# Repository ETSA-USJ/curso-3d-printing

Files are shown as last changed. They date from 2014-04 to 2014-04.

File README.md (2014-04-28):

Curso 3D printing: Montaje de una Prusa Mendel IT2
============================================

Curso 2031-14
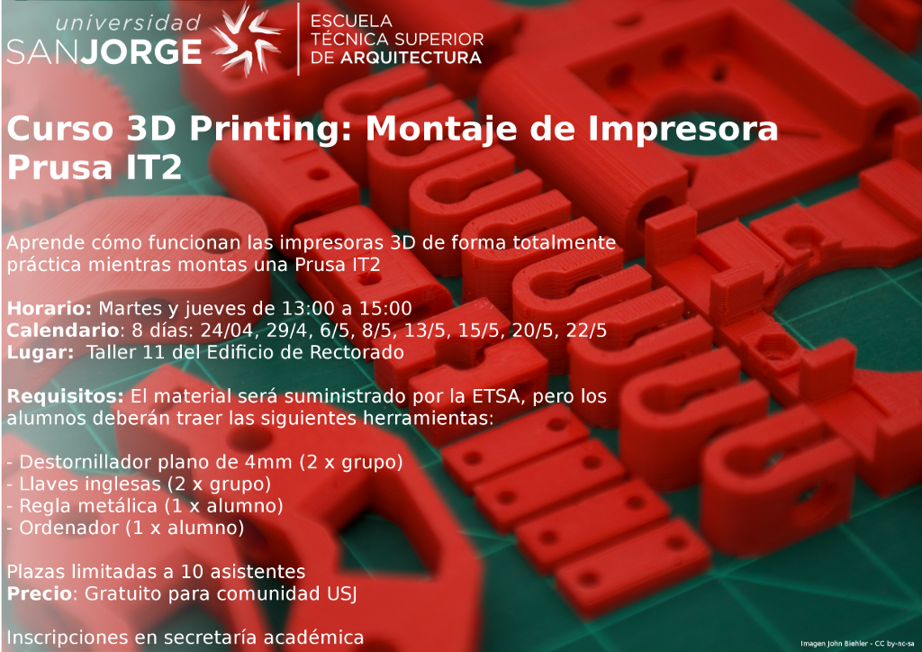
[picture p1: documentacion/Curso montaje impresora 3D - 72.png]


### Responsables del curso
* David Álvarez
* Javier Álvarez
* Carlos Cámara
* Antonio Estepa

## Documentación

* [Piezas Prusa Mendel IT2 (Fuente: Clone Wars)](http://www.reprap.org/wiki/Clone_wars:_Prusa_Iteraci%C3%B3n_2)
* [Guía de montaje (Fuente: IEA Robotics)](http://www.iearobotics.com/wiki/index.php?title=Guia_de_montaje_de_la_Prusa_2)
* [Thingiverse](http://www.thingiverse.com)

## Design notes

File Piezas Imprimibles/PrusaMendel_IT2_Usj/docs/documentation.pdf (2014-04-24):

## Prusa Mendel iteration 2 Documentation

ThingDoc

November 16, 2011

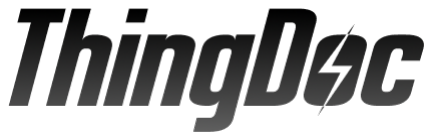
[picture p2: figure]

Prusa Mendel is simplified version of Mendel form RepRap project. RepRap is open source 3D printer.

## Contents

## 1 Bill of Materials

List of things you need to build the machine divided by categories.

### 1.1 Rods and Bars

- 1x Idler

### 1.2 Nuts&bolts

- 3x 608 skate bearing
- 4x M4 nut
- 3x M3 10mm screw
- 2x M4 25mm screw
- 1x M8 hobbed bolt
- 8x M3 15mm screw with HEX head
- 2x M3 10mm screw with hex head
- 1x M3 25mm screw
- 1x M3 grub screw
- 2x M3 25mm screw with HEX head
- 12x M3 nut
- 73x M8 washer
- 74x M8 nut
- 29x M3 washer
- 1x M3 10mm screw with flat head
- 2x M3 40mm screw

### 1.3 Printed

- 1x Extruder body
- 8x Bar clamp
- 4x Y bushing
- 2x Frame vertex
- 1x Y motor bracket
- 1x Small extruder gear

- 2x Rod clamp
- 4x Frame vertex with foot
- 1x Large extruder gear
- 2x Belt clamp
- 1x Extruder Idler
- 1x Z motor mount
- 1x X carriage

## 2 Things Overview

List of things and their descriptions.

### 2.1 Coupling tube

20mm long piece of PVC tube. 5mm inside diameter, 8mm outside diameter.

### 2.2 Frame triangle

Two triangle parts which will later form a frame.

### 2.3 Frame with axes

Frame with all axes mounted

### 2.4 Frame vertex

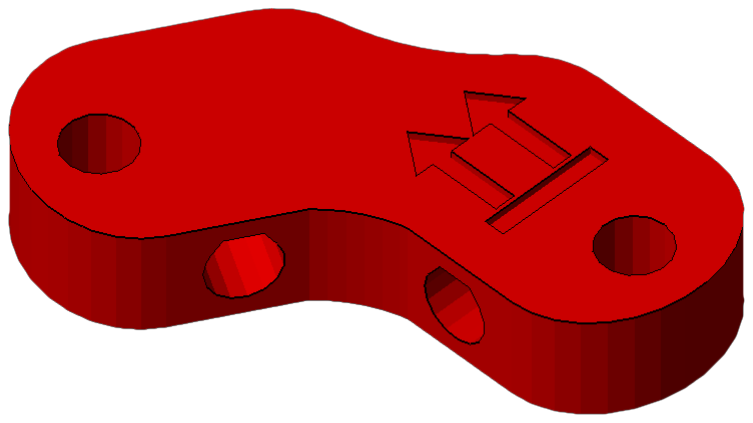
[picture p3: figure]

### 2.5 Frame

Frame for adding all of the other parts There is a triangle on each side of the Prusa RepRap. You will need to make two of these and then connect them together (in the next steps) to form the Prusa frame. Each side is an equilateral triangle with a frame vertex on each corner. You can use either footed or non-footed vertices to build this. (The footed ones look better, but are not critical.) The instructions assume you are using footed vertices.

### 2.6 Y motor bracket

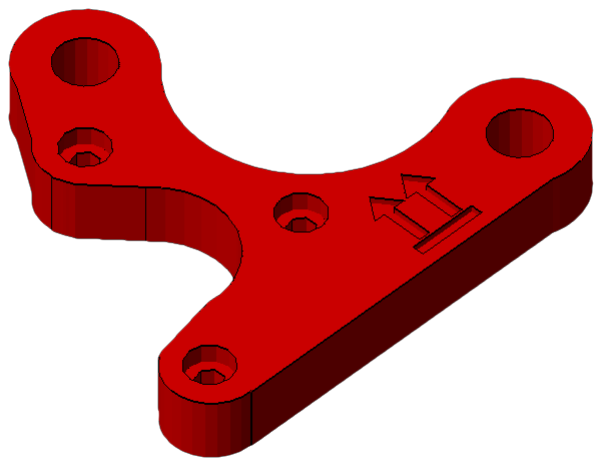
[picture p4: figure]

### 2.7 Belt clamp

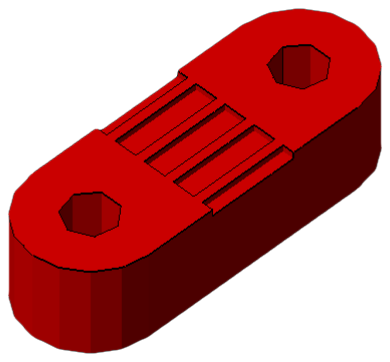
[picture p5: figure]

### 2.8 M8 hobbed bolt

### 2.9 Extruder Idler

Extruder idler

### 2.10 Frame with Y axis

Frame with Y axis mounted

### 2.11 Y bushing

### 2.12 Bar clamp

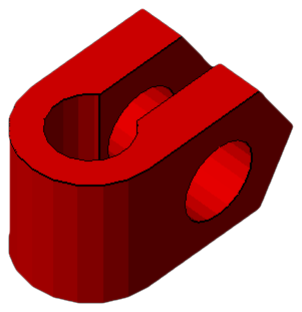
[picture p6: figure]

### 2.13 XZ axis

Assembled XZ axis

### 2.14 Large extruder gear

### 2.15 Frame vertex with foot

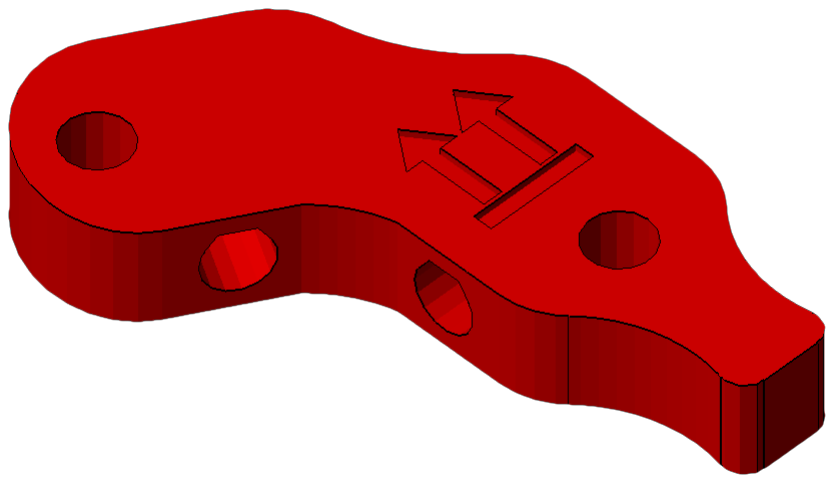
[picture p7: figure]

### 2.16 X end motor

### 2.17 Extruder body

Extruder body

### 2.18 Small extruder gear

### 2.19 Extruder spring

Spring used for idler on extruder.

### 2.20 Printable Bushing

### 2.21 X carriage

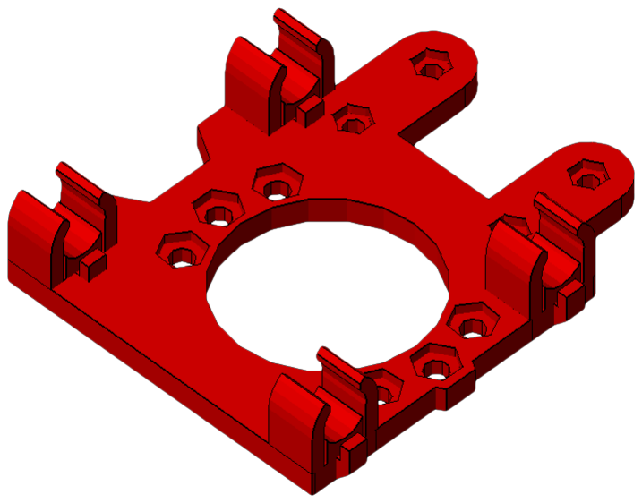
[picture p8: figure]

### 2.22 X end idler

### 2.23 Rod clamp

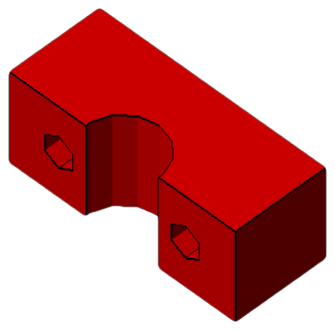
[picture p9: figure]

### 2.24 Z motor mount

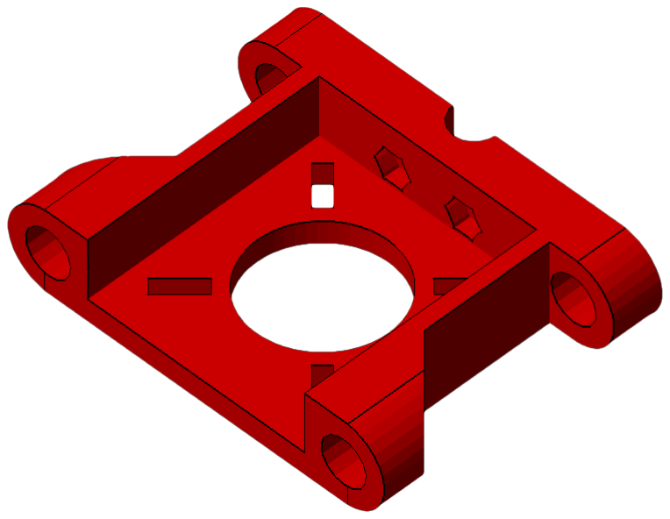
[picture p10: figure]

### 2.25 Endstop holder

### 2.26 Bushing

### 2.27 Idler

Small M8 rod

### 2.28 Pulley

### 2.29 Coupling

### 2.30 Y axis

Assembled Y axis

### 2.31 Bearing guide

Helps to hold belt aligned on the bearing.

### 2.32 Carriage

X-carriage with mounted extruder

### 2.33 Extruder

Extruder

## 3 Assembly Instructions

### 3.1 Assemble Small extruder gear

Things needed:

- 1x M3 nut
- 1x M3 grub screw

Steps:

1. Insert nut into cavity in printed gear.
2. Tighten the grub screw a bit, just to hold in place.

### 3.2 Assemble M8 hobbed bolt

Steps:

1. Use thread cutting bit in electric screwdriver ...

### 3.3 Assemble Large extruder gear

Things needed:

- 1x M8 hobbed bolt

Steps:

1. Insert hobbed bolt into main hole.
2. Add some M8 washers from other side, later with their count you adjust position of hobbed part in filament path.

### 3.4 Assemble Extruder Idler

Things needed:

- 1x 608 skate bearing
- 1x Idler

Steps:

1. Insert piece of M8 rod into bearing.
2. Insert 608 bearing with rod into printed idler part.

### 3.5 Assemble Extruder

Things needed:

- 2x 608 skate bearing
- 1x Extruder body
- 3x M3 10mm screw
- 2x M4 nut
- 1x Small extruder gear
- 1x M3 25mm screw
- 1x NEMA17 stepper motor
- 1x Large extruder gear
- 8x M3 washer
- 1x M8 washer
- 1x Extruder Idler
- 1x M3 nut
- 2x M3 40mm screw
- 2x Extruder spring
- 2x M8 nut

Steps:

1. Take idler and insert nut into small nut-trap inside the hinge.
2. While holding the nut in place, preprare M3x25 bolt with washer and screw it into the hinge just enough to hold the nut.
3. Now take the extruder body and idler. Place idler on the hinge counterpart and com-pleately screw the M3x25 bolt. This will create secured hinge.
4. Place M4 nuts into their nut traps, secure them with piece of tape. We need them in place, since later they would be harder to access.
5. Prepare your NEMA17 stepper motor and three M3x10 screws with washers.
6. Hold motor on place and lightly tighten the screws. We need to adjust motor position later, no need to tighten it hard.
7. Place two skate bearings on ther position, they should snuggly fit in.
8. Insert prepared large gear into the body with mounted bearings.

9. Check if the alignment of hobbed part with the filament path. Adjust it accordingly with adding or removing M8 washers.
10. After adjusting, we need to fix the bolt in. So we place washer at the end of hobbed bolt and with two M8 nuts we will do locknut by tightening them against each other.
11. Check if large gear turns freely.
12. Prepare two M3x40 screws with sandwitch of washer-spring-washer.
13. Insert two M3 nuts into nut traps on top of drive mechanism.

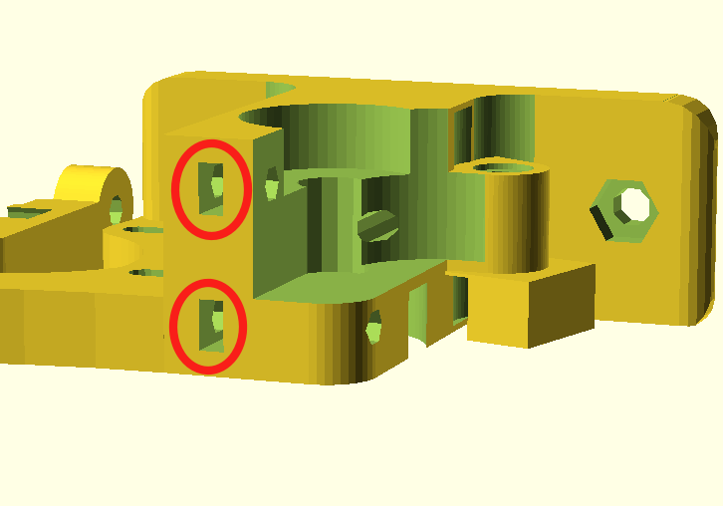
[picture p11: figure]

14. Insert prepared screws into the holes on idler. Close the idler and tighten the screws into the trapped nuts. More you tighten those screws, more pressure will be on fillament.
15. Your extruder is done.

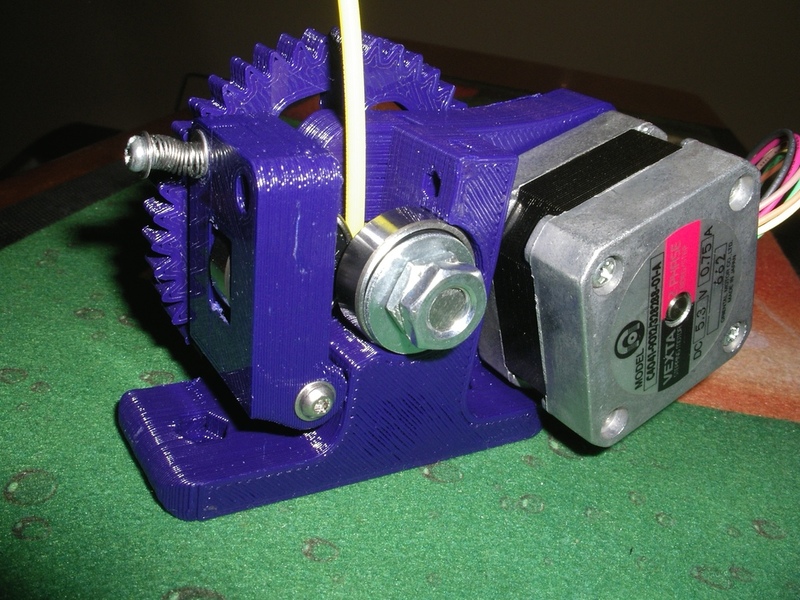
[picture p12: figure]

### 3.6 Assemble Frame triangle

Things needed:

- 1x Bar clamp
- 1x Frame vertex
- 2x Frame vertex with foot

Steps:

1. Take one of the 370mm threaded rods, and slip an M8 washer onto the middle of it.
2. Take the RP bar clamp (the U-shaped bit with the two holes) and slide the threaded rod through the two holes until the clamp sits next to the washer.
3. Slide another washer onto the rod from the other side.
4. Thread two M8 nuts onto either side of the clamp, until they are next to the washer, but do not tighten them yet.

5. Thread another two nuts on each side of the rod, followed by washers. See the picture for what it should look like.

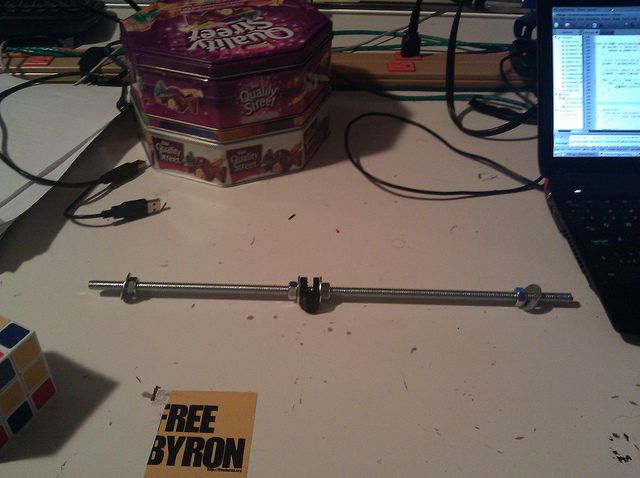
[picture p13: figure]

6. The bar clamp on the threaded rod.
7. Slide the rod through the wider bottom (footed) side of two vertices. Make sure the feet point in the same direction, and the bulge on the non-footed sides of the vertices point outwards.
8. Measure the distance. The distance between the two vertices should be 290mm (along the rod, equivalent is 11-13/32”). Get it approximately right now, we will check this again later. If you have a frame jig, place it between the two vertices and adjust the nuts until you can just barely fit the jig J1 between them.
9. Place another washer and nut on the other side of the vertex. Tighten, but not too much. We’ll need a bit of flexibility here still.
10. Take another 370mm M8 threaded rod and place a nut followed by a washer at each end.
11. Place one end of the threaded rod into the one of the two footed frame vertices. It should be in the same plane as the first threaded rod. Fix it in place with a washer and nut. You should now have two sides of the equilateral triangle.
12. Take the third piece of threaded rod and put a nut and washer on each end. Place it in the other footed vertex and fix it in place with a washer and nut. You should now have a triangle of threaded rods with two footed vertices on two of the corners, nothing in the third corner, and a bar clamp between the two vertices.
13. Take the third vertex (non-footed) and slide it onto the threaded rods in the final corner of the triangle. Measure the lengths of the three sides to make sure they are all 290mm long (along the rod from plastic part to plastic part, equivalent is 11-13/32”). Adjust the nuts to make sure this is so. Use the frame jig J1 if you have one. Once done, place a washer and nut on each of the two rods at the top of the vertex. Tighten all the outer nuts.
14. The finished frame triangle
15. You should now have a sturdy triangle with equal-length sides, two feet on the bottom, and a bar clamp between the feet. Adjust the nuts around the bar clamp (but do not crush the bar clamp together yet) until it’s approximately in the middle of the rod. Leave the nuts there loose. See the photo for what you should have at this point.

16. That’s it, that’s one of the triangles done. Repeat the entire procedure for the second triangle. It is identical to the first.

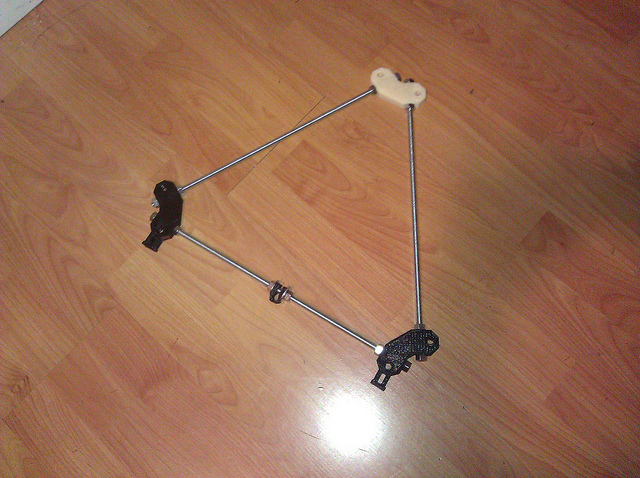
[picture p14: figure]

### 3.7 Assemble Prusa Mendel iteration 2

Things needed:

- 1x Carriage
- 1x Frame with axes

Steps:

1. Assembly info

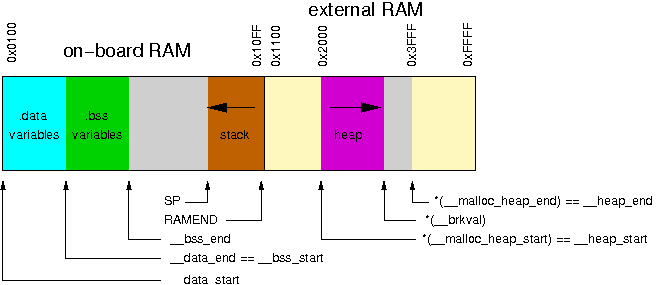
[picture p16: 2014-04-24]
Software/Arduino/Mac/Arduino 1.0.5.app/Contents/Resources/Java/hardware/tools/avr/doc/avr-libc/malloc-x2.png

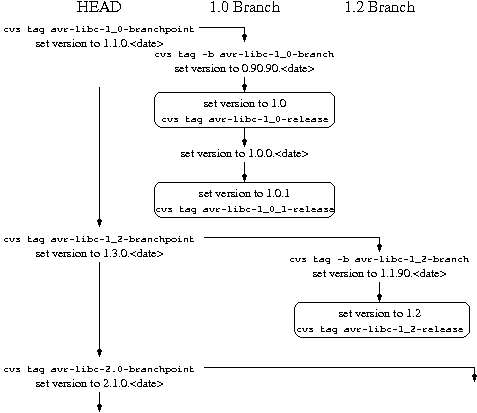
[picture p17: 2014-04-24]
Software/Arduino/Mac/Arduino 1.0.5.app/Contents/Resources/Java/hardware/tools/avr/doc/avr-libc/releases.png

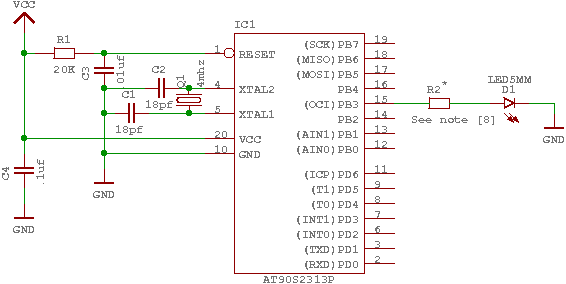
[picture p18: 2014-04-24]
Software/Arduino/Mac/Arduino 1.0.5.app/Contents/Resources/Java/hardware/tools/avr/doc/avr-libc/demo.png

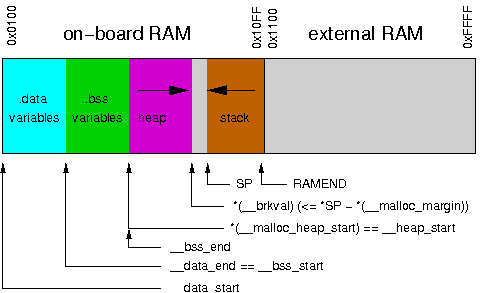
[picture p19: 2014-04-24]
Software/Arduino/Mac/Arduino 1.0.5.app/Contents/Resources/Java/hardware/tools/avr/doc/avr-libc/malloc-std.png

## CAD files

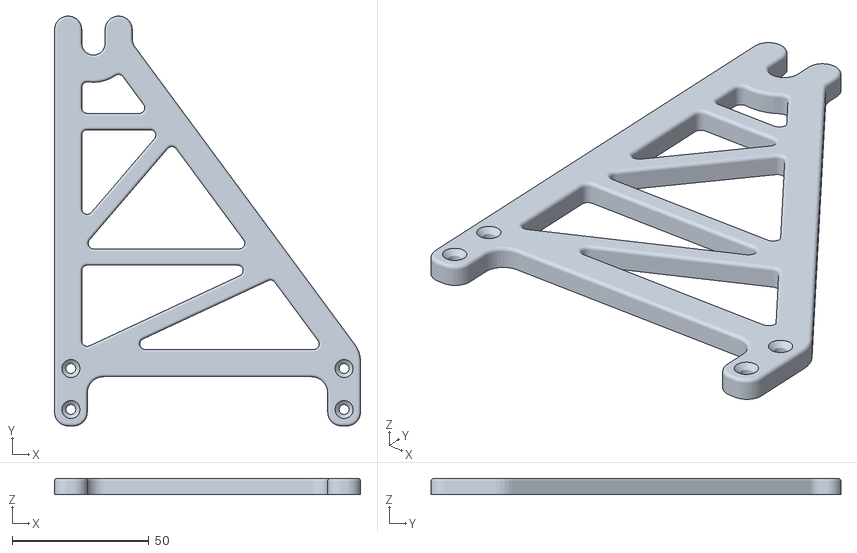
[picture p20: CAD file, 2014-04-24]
Piezas Imprimibles/Ampliaciones/Soporte Bobina/SPOOL_ARM_LEFT.stl
112.0 x 150.0 x 6.00

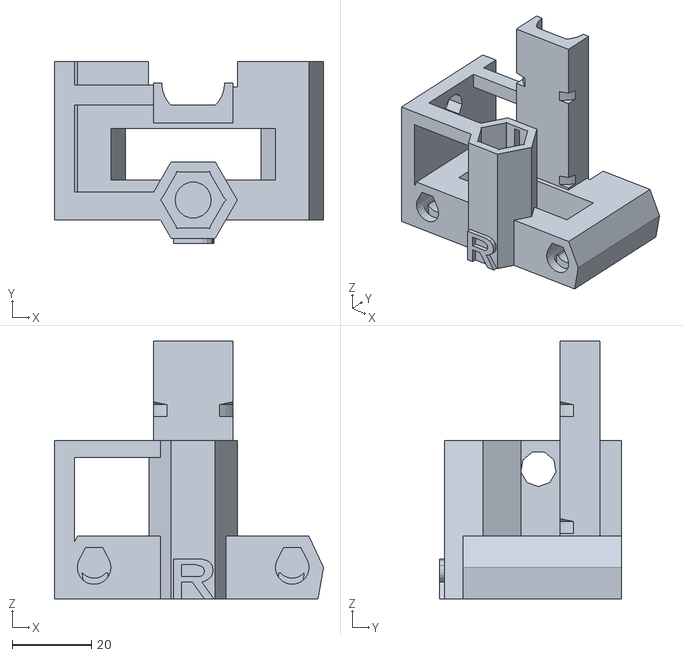
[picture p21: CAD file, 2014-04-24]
Piezas Imprimibles/PrusaMendel_IT2_Usj/metric-prusa-lm8uu/x-end-idler.stl
67.9 x 46.0 x 65.0

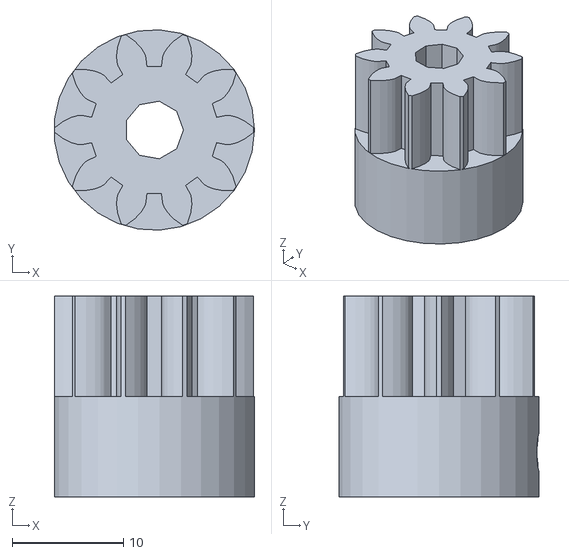
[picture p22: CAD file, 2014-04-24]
Piezas Imprimibles/PrusaMendel_IT2_Usj/metric-prusa-lme8uu/wade-small.stl
17.9 x 18.0 x 18.0

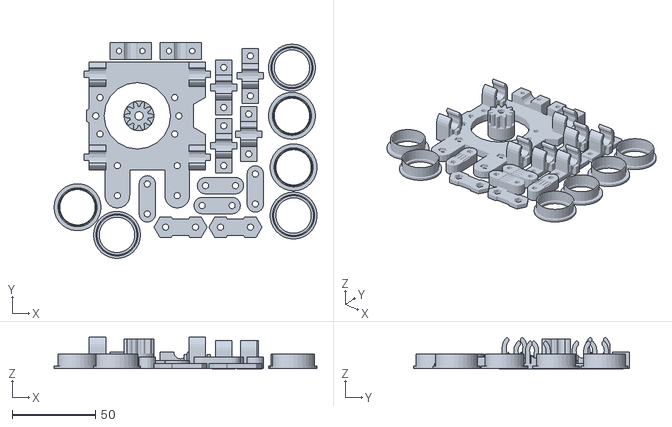
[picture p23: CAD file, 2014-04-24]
Piezas Imprimibles/PrusaMendel_IT2_Usj/metric-prusa/mendel-plate-4.stl
158.2 x 129.7 x 19.0

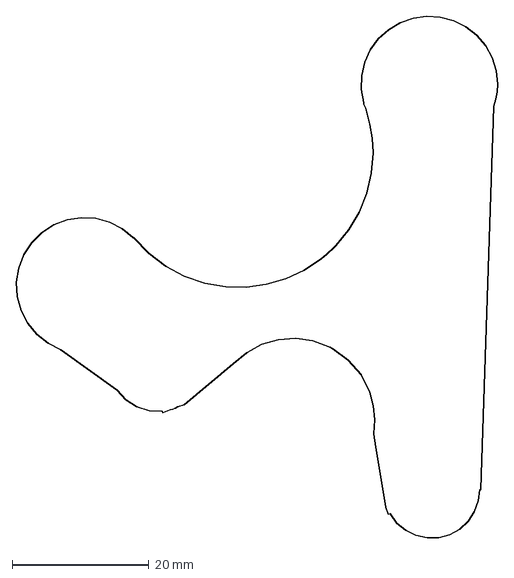
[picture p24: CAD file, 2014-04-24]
Piezas Imprimibles/PrusaMendel_IT2_Usj/source/ybrac-t.dxf
70.5 x 76.4 mm

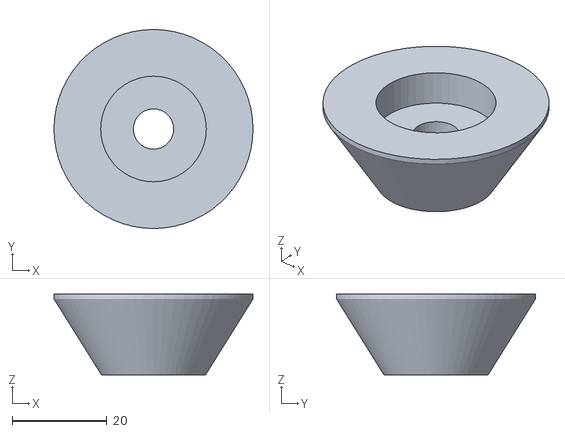
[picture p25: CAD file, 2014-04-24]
Piezas Imprimibles/Ampliaciones/Soporte Bobina/reprap_spool_spindle.STL
42.0 x 42.0 x 17.0

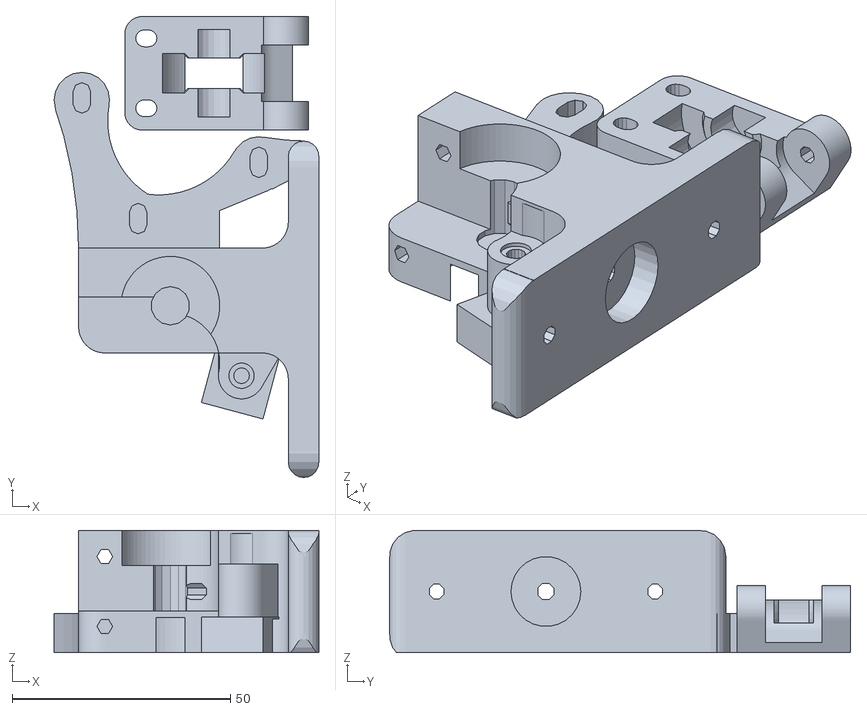
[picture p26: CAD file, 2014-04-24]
Piezas Imprimibles/PrusaMendel_IT2_Usj/metric-prusa-lm8uu/wade.stl
60.6 x 105.5 x 28.0

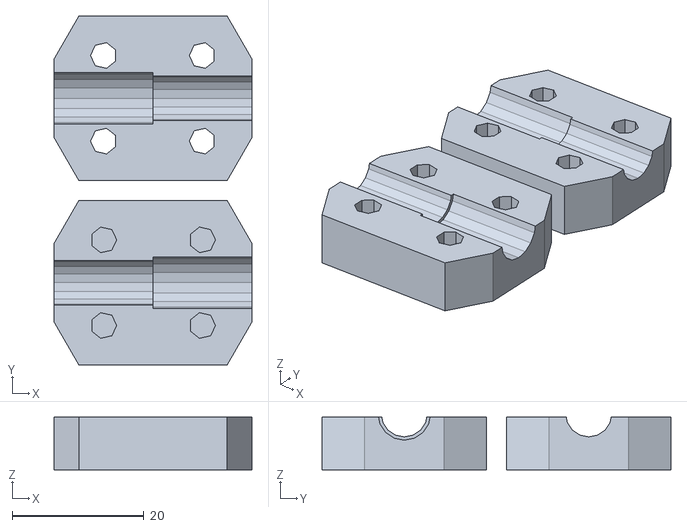
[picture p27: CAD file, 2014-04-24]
Piezas Imprimibles/PrusaMendel_IT2_Usj/metric-prusa-lme8uu/coupling.stl
30.0 x 53.0 x 8.00

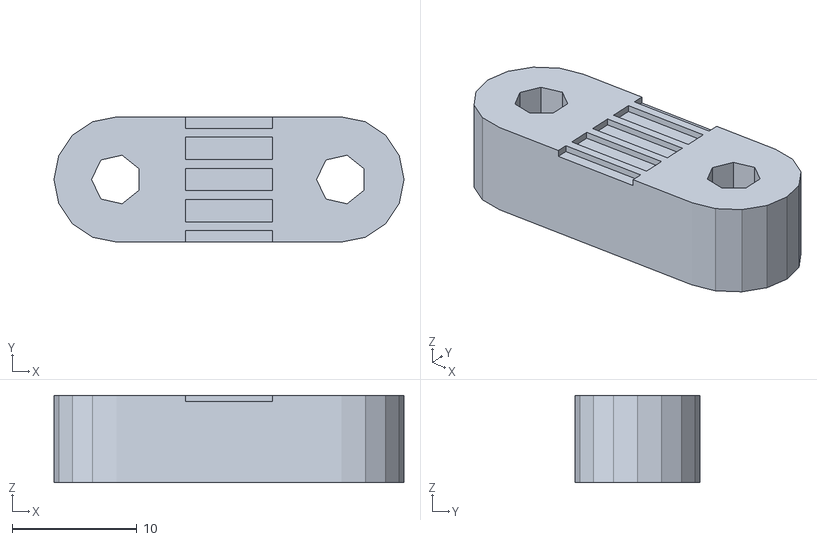
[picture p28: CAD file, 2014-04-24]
Piezas Imprimibles/PrusaMendel_IT2_Usj/metric-prusa/belt-clamp.stl
28.0 x 10.0 x 7.00

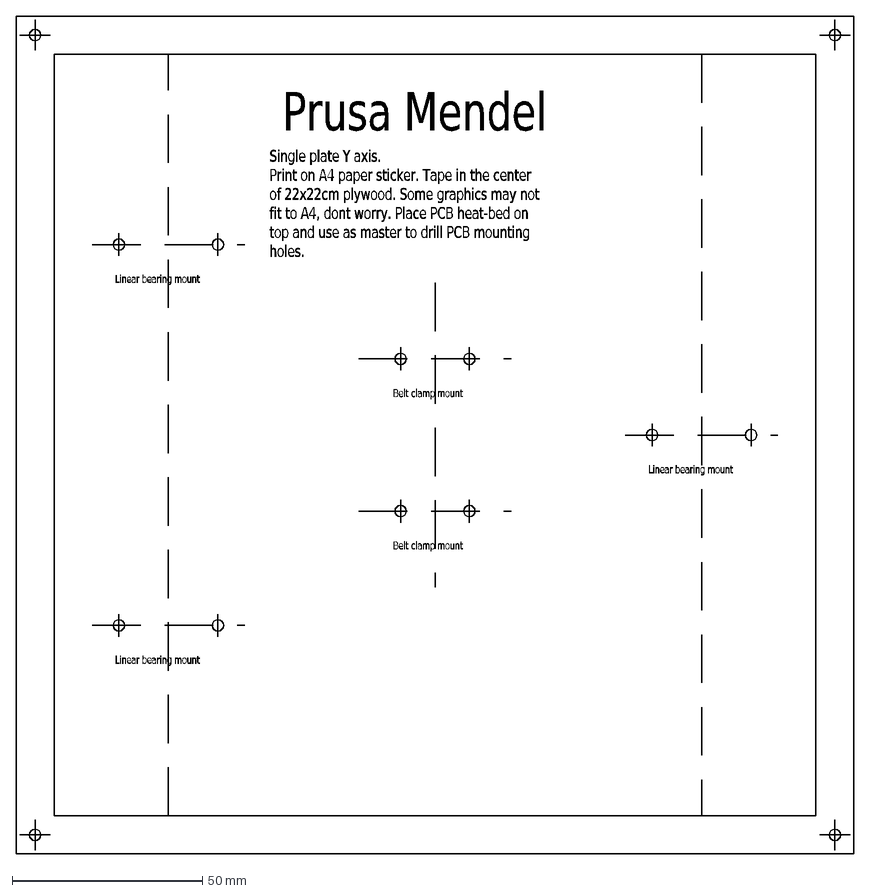
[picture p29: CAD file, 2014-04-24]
Piezas Imprimibles/PrusaMendel_IT2_Usj/source/bed-drilling.dxf
Prusa\~Mendel
Single\~plate\~Y\~axis. Print\~on\~A4\~paper\~sticker.\~Tape\~in\~the\~center\~ of\~22x22cm\~plywood.\~Some\~graphics\~may\~not fit\~to\~A4,\~dont\~worry.\~Plac
Linear\~bearing\~mount
Belt\~clamp\~mount

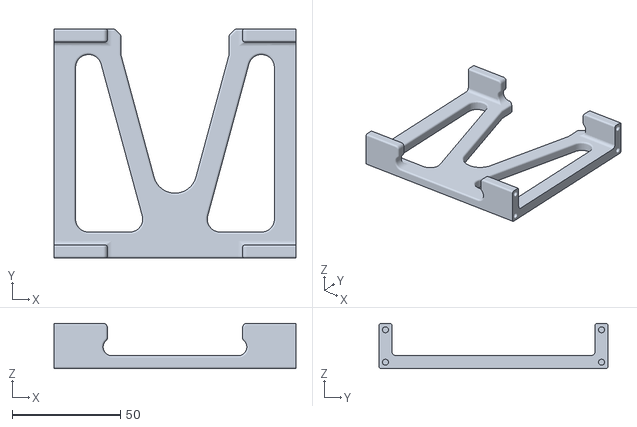
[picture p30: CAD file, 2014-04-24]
Piezas Imprimibles/Ampliaciones/Soporte Bobina/CLIP-ON_BASE.stl
112.0 x 106.0 x 21.0

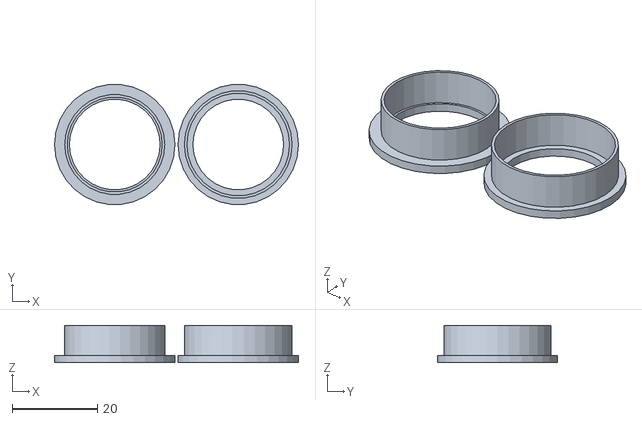
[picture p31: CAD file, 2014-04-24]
Piezas Imprimibles/PrusaMendel_IT2_Usj/metric-prusa-lm8uu/bearing-guide.stl
57.3 x 28.1 x 8.70

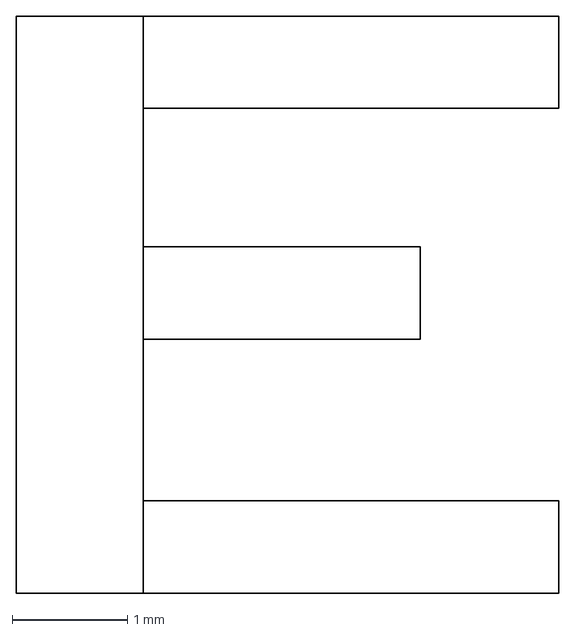
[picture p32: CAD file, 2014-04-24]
Piezas Imprimibles/PrusaMendel_IT2_Usj/source/this-way-up.dxf
4.70 x 5.00 mm

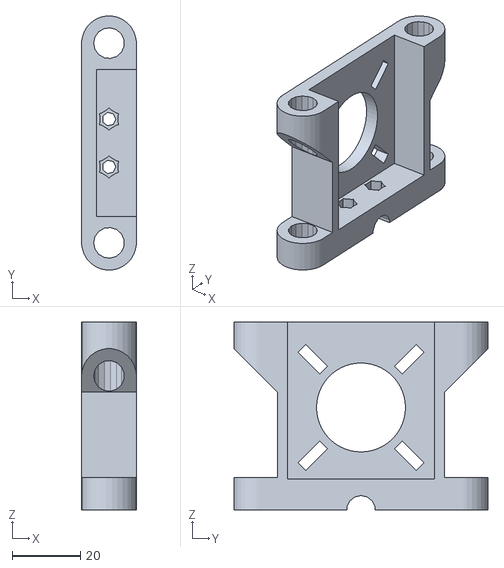
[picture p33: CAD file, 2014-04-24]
Piezas Imprimibles/PrusaMendel_IT2_Usj/metric-prusa-lm8uu/z-motor-mount.stl
16.0 x 74.4 x 55.0

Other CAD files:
Piezas Imprimibles/Ampliaciones/Soporte Bobina/SPOOL_ARM_RIGHT.stl
Piezas Imprimibles/PrusaMendel_IT2_Usj/metric-prusa-lme8uu/ybrac-t.stl
Piezas Imprimibles/PrusaMendel_IT2_Usj/metric-prusa/printable-bushing-lm8uu.stl
Piezas Imprimibles/PrusaMendel_IT2_Usj/source/configuration.scad
Piezas Imprimibles/PrusaMendel_IT2_Usj/source/inc/parametric_involute_gear_v5.0.scad
Piezas Imprimibles/PrusaMendel_IT2_Usj/source/x-end-motor.scad
Piezas Imprimibles/PrusaMendel_IT2_Usj/source/z-motor-mount.scad
Piezas Imprimibles/PrusaMendel_IT2_Usj/metric-prusa-lm8uu/bar-clamp.stl
Piezas Imprimibles/PrusaMendel_IT2_Usj/metric-prusa-lm8uu/belt-clamp-nut-holder.stl
Piezas Imprimibles/PrusaMendel_IT2_Usj/metric-prusa-lm8uu/endstop-holder.stl
Piezas Imprimibles/PrusaMendel_IT2_Usj/metric-prusa-lm8uu/frame-vertex-foot.stl
Piezas Imprimibles/PrusaMendel_IT2_Usj/metric-prusa-lm8uu/frame-vertex.stl
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

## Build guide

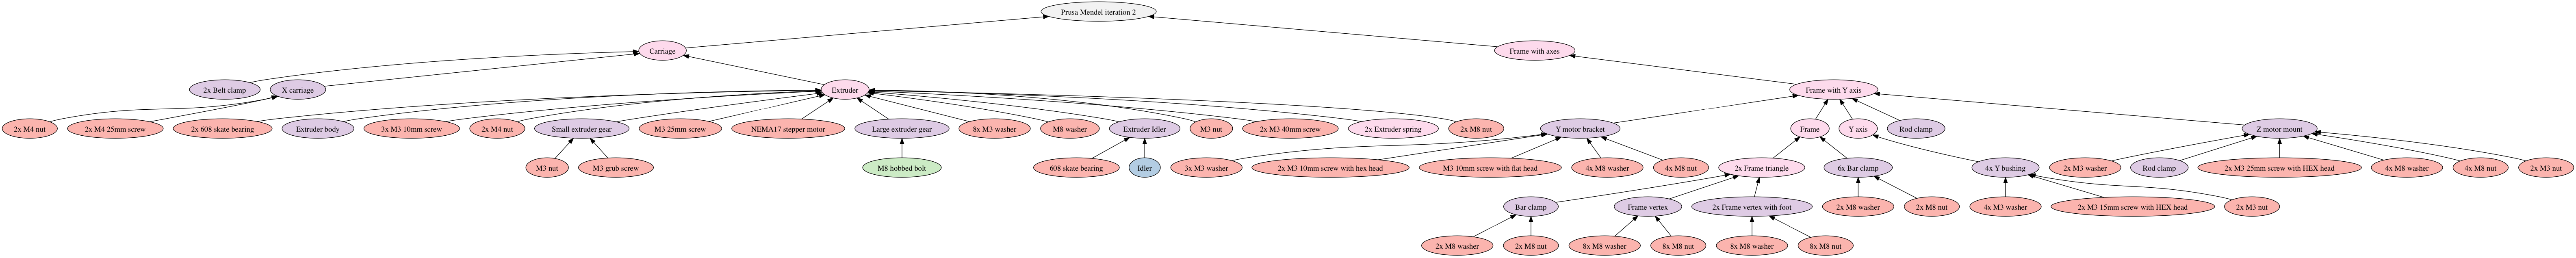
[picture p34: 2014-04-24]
Piezas Imprimibles/PrusaMendel_IT2_Usj/docs/assembly-graph.png

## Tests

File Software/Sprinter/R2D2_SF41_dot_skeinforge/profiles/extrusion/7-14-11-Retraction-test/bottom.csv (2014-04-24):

Format is tab separated bottom settings.
_Name | Value
WindowPosition | 700+0
Open File for Bottom
Activate Bottom | False
Additional Height over Layer Thickness (ratio): | 0.7
Altitude (mm): | 0.0
SVG Viewer: | webbrowser

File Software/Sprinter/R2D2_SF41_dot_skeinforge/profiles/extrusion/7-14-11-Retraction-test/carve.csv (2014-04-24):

Format is tab separated carve settings.
_Name | Value
WindowPosition | 700+0
Open File for Carve
Add Layer Template to SVG | True
Extra Decimal Places (float): | 2.0
Import Coarseness (ratio): | 1.0
Infill in Direction of Bridge | True
Layer Thickness (mm): | 0.28
Layers From (index): | 0
Layers To (index): | 912345678
Correct Mesh | True
Unproven Mesh | False
Perimeter Width over Thickness (ratio): | 2.1
SVG Viewer: | webbrowser

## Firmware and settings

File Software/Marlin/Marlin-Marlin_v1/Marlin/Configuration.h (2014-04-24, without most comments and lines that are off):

#define CONFIGURATION_H
#define STRING_VERSION_CONFIG_H __DATE__ " " __TIME__ // build date and time
#define STRING_CONFIG_H_AUTHOR "(none, default config)" // Who made the changes.
#define SERIAL_PORT 0
#define BAUDRATE 250000
#define MOTHERBOARD 33
#define EXTRUDERS 1
#define POWER_SUPPLY 1
#define TEMP_SENSOR_0 5
#define TEMP_SENSOR_1 0
#define TEMP_SENSOR_2 0
#define TEMP_SENSOR_BED 1
#define MAX_REDUNDANT_TEMP_SENSOR_DIFF 10
#define TEMP_RESIDENCY_TIME 10  // (seconds)
#define TEMP_HYSTERESIS 3       // (degC) range of +/- temperatures considered "close" to the target one
#define TEMP_WINDOW     1       // (degC) Window around target to start the residency timer x degC early.
#define HEATER_0_MINTEMP 5
#define HEATER_1_MINTEMP 5
#define HEATER_2_MINTEMP 5
#define BED_MINTEMP 5
#define HEATER_0_MAXTEMP 275
#define HEATER_1_MAXTEMP 275
#define HEATER_2_MAXTEMP 275
#define BED_MAXTEMP 150
#define PIDTEMP
#define BANG_MAX 255 // limits current to nozzle while in bang-bang mode; 255=full current
#define PID_MAX 255 // limits current to nozzle while PID is active (see PID_FUNCTIONAL_RANGE below); 255=full current
  #define PID_FUNCTIONAL_RANGE 10 // If the temperature difference between the target temperature and the actual temperature
  #define PID_INTEGRAL_DRIVE_MAX 255  //limit for the integral term
  #define K1 0.95 //smoothing factor within the PID
  #define PID_dT ((16.0 * 8.0)/(F_CPU / 64.0 / 256.0)) //sampling period of the temperature routine
    #define  DEFAULT_Kp 22.2
    #define  DEFAULT_Ki 1.08
    #define  DEFAULT_Kd 114
#define MAX_BED_POWER 255 // limits duty cycle to bed; 255=full current
#define PREVENT_DANGEROUS_EXTRUDE
#define PREVENT_LENGTHY_EXTRUDE
#define EXTRUDE_MINTEMP 170
#define EXTRUDE_MAXLENGTH (X_MAX_LENGTH+Y_MAX_LENGTH) //prevent extrusion of very large distances.
#define ENDSTOPPULLUPS // Comment this out (using // at the start of the line) to disable the endstop pullup resistors
  #define ENDSTOPPULLUP_XMAX
  #define ENDSTOPPULLUP_YMAX
  #define ENDSTOPPULLUP_ZMAX
  #define ENDSTOPPULLUP_XMIN
  #define ENDSTOPPULLUP_YMIN
  #define ENDSTOPPULLUP_ZMIN
const bool X_MIN_ENDSTOP_INVERTING = true; // set to true to invert the logic of the endstop.
const bool Y_MIN_ENDSTOP_INVERTING = true; // set to true to invert the logic of the endstop.
const bool Z_MIN_ENDSTOP_INVERTING = true; // set to true to invert the logic of the endstop.
const bool X_MAX_ENDSTOP_INVERTING = true; // set to true to invert the logic of the endstop.
const bool Y_MAX_ENDSTOP_INVERTING = true; // set to true to invert the logic of the endstop.
const bool Z_MAX_ENDSTOP_INVERTING = true; // set to true to invert the logic of the endstop.
#if defined(COREXY) && !defined(DISABLE_MAX_ENDSTOPS)
  #define DISABLE_MAX_ENDSTOPS
#endif
#define X_ENABLE_ON 0
#define Y_ENABLE_ON 0
#define Z_ENABLE_ON 0
#define E_ENABLE_ON 0 // For all extruders
#define DISABLE_X false
#define DISABLE_Y false
#define DISABLE_Z false
#define DISABLE_E false // For all extruders
#define INVERT_X_DIR true    // for Mendel set to false, for Orca set to true
#define INVERT_Y_DIR false    // for Mendel set to true, for Orca set to false
#define INVERT_Z_DIR true     // for Mendel set to false, for Orca set to true
#define INVERT_E0_DIR false   // for direct drive extruder v9 set to true, for geared extruder set to false
#define INVERT_E1_DIR false    // for direct drive extruder v9 set to true, for geared extruder set to false
#define INVERT_E2_DIR false   // for direct drive extruder v9 set to true, for geared extruder set to false
#define X_HOME_DIR -1
#define Y_HOME_DIR -1
#define Z_HOME_DIR -1
#define min_software_endstops true // If true, axis won't move to coordinates less than HOME_POS.
#define max_software_endstops true  // If true, axis won't move to coordinates greater than the defined lengths below.
#define X_MAX_POS 205
#define X_MIN_POS 0
#define Y_MAX_POS 205
#define Y_MIN_POS 0
#define Z_MAX_POS 200
#define Z_MIN_POS 0
#define X_MAX_LENGTH (X_MAX_POS - X_MIN_POS)
#define Y_MAX_LENGTH (Y_MAX_POS - Y_MIN_POS)
#define Z_MAX_LENGTH (Z_MAX_POS - Z_MIN_POS)
#define MANUAL_X_HOME_POS 0
#define MANUAL_Y_HOME_POS 0
#define MANUAL_Z_HOME_POS 0
#define NUM_AXIS 4 // The axis order in all axis related arrays is X, Y, Z, E
#define HOMING_FEEDRATE {50*60, 50*60, 4*60, 0}  // set the homing speeds (mm/min)
#define DEFAULT_AXIS_STEPS_PER_UNIT   {78.7402,78.7402,200.0*8/3,760*1.1}  // default steps per unit for Ultimaker
#define DEFAULT_MAX_FEEDRATE          {500, 500, 5, 25}    // (mm/sec)
#define DEFAULT_MAX_ACCELERATION      {9000,9000,100,10000}    // X, Y, Z, E maximum start speed for accelerated moves. E default values are good for skeinforge 40+, for older versions raise them a lot.
#define DEFAULT_ACCELERATION          3000    // X, Y, Z and E max acceleration in mm/s^2 for printing moves
#define DEFAULT_RETRACT_ACCELERATION  3000   // X, Y, Z and E max acceleration in mm/s^2 for retracts
#define DEFAULT_XYJERK                20.0    // (mm/sec)
#define DEFAULT_ZJERK                 0.4     // (mm/sec)
#define DEFAULT_EJERK                 5.0    // (mm/sec)
#define PLA_PREHEAT_HOTEND_TEMP 180
#define PLA_PREHEAT_HPB_TEMP 70
#define PLA_PREHEAT_FAN_SPEED 255   // Insert Value between 0 and 255
#define ABS_PREHEAT_HOTEND_TEMP 240
#define ABS_PREHEAT_HPB_TEMP 100
#define ABS_PREHEAT_FAN_SPEED 255   // Insert Value between 0 and 255
#define SOFT_PWM_SCALE 0
#include "Configuration_adv.h"
#include "thermistortables.h"

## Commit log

2014-04-28 Añadida carpeta de documentación del curso
2014-04-28 Limpieza de archivos ocultos de mac
